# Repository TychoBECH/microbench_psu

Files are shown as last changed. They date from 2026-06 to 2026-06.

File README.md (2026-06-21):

# Bench PSU

A bench power supply built around a PIC18F16Q40, split across three boards: a main board (power supply, MCU, USB), a UI board (rotary encoder + buttons), and a display board (7-segment display + LEDs). Voltage (0-24 V) and current (0-2 A) are set via the encoder and a DAC, with live measurement readback through three I2C ADCs. Firmware features include EEPROM-backed setpoint persistence, automatic over-temperature shutdown, a standby/sleep mode, and a SCPI-style ASCII command interface over UART for remote control and automated testing. The enclosure is 3D-printed.

## Repository structure

```
firmware/microbench_psu.X/      MPLAB X project (PIC18F16Q40, XC8)
hardware/electrical/            Altium Designer projects, one per board
  main-board/                     Power supply, MCU, USB
    Parts_Library/                  Shared component library (git submodule)
  ui-board/                       Rotary encoder and buttons
  display-board/                  7-segment display and LEDs
hardware/mechanical/            SolidWorks enclosure and 3D-printed parts
hardware/bom/                   Bill of materials
docs/                            Pinout tables, SCPI command reference, notes
```

## Building the firmware

Open `firmware/microbench_psu.X` in MPLAB X IDE and build as usual. The project uses MPLAB Code Configurator (MCC) generated drivers under `mcc_generated_files/`, plus a set of hand-written modules (`display`, `encoder`, `adc`, `psu`, `eeprom_settings`, `scpi`, `i2c_bus`, `mcp47cxdx`) — see `firmware/microbench_psu.X/main.c` for the top-level control flow.

## Hardware

Each board under `hardware/electrical/` is its own Altium Designer project; see the README in each board's folder for what it covers. The main board references a shared component library as a git submodule — after cloning this repo, run:

```
git submodule update --init --recursive
```

to pull it in.

`hardware/mechanical/` holds the SolidWorks enclosure (front/back covers, knob, lightpipe) with STL/STEP exports for printing or referencing in other CAD tools.

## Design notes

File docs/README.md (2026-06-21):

# Documentation

- [SCPI command reference](scpi-reference.md) — UART command interface for remote control and automated testing

Pinout tables and other notes go here.

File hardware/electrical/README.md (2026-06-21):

# Electrical

Three separate Altium Designer projects, one per board:

| Folder | Board |
|---|---|
| `main-board/` | Power supply, MCU, USB |
| `ui-board/` | Encoder and buttons |
| `display-board/` | Display and LEDs |

Each board folder holds its own Altium project files (`.PrjPcb`, `.SchDoc`, `.PcbDoc`, etc.) plus an `outputs/` subfolder for generated manufacturing/assembly outputs (gerbers, NC drill files, STEP exports). Treat `outputs/` as regenerable, not source of truth.

The main board references a shared component library (schematic symbols, PCB footprints, 3D models) as a git submodule at `main-board/Parts_Library/`, pulled from a separate repo. After cloning, run `git submodule update --init --recursive` to fetch it.

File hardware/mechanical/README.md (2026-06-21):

# Mechanical

SolidWorks enclosure for the PSU.

- `Assembly_microbench_psu.SLDASM` — top-level assembly
- `Front Cover.SLDPRT`, `Back Cover.SLDPRT` — main enclosure shells
- `Knob.SLDPRT` — encoder knob
- `Lightpipe.SLDPRT` — light pipe for the front panel LEDs

## exports/

Print-ready and interchange exports. Treat this as regenerable output, not source of truth.

- `stl/` — print-ready meshes for the enclosure parts (covers, bezel, case, knob)
- `stp/` — STEP exports, including board outlines imported from each Altium project (`main-board.step`, `ui-board.step`, `display-board.step`) for mechanical fit-checking, plus third-party part models (e.g. `1455J801BK.step` for the enclosure base)

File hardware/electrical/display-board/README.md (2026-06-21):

# Display board

7-segment display and LEDs.

Altium project: `display-board.PrjPcb` / `display-board.PcbDoc` / `display-board.SchDoc`.

Generated outputs (gerbers, NC drill files, STEP export) are in `outputs/`.

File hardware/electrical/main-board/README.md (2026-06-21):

# Main board

Power supply (DC/DC conversion, adjustable output stage), MCU (PIC18F16Q40), and USB.

Altium project: `main-board.PrjPcb` / `main-board.PcbDoc`, with schematic sheets covering the overview, the adjustable DC/DC converter, the output stage, and USB. References the shared `Parts_Library/` submodule for schematic symbols, footprints, and 3D models.

Generated outputs (gerbers, NC drill files, STEP export) are in `outputs/`.

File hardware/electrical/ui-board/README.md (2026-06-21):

# UI board

Rotary encoder and buttons.

Altium project: `ui-board.PrjPcb` / `ui-board.PcbDoc` / `ui-board.SchDoc`.

Generated outputs (gerbers, NC drill files, STEP export) are in `outputs/`.

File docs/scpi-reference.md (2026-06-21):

# SCPI command reference

The firmware exposes a SCPI-style ASCII command interface over UART1.

## Line format

- Commands are terminated with `\r`, `\n`, or both.
- Commands are case-insensitive (the parser uppercases the line before matching).
- Numeric arguments are decimal, e.g. `12.5`, with up to 3 fractional digits; extra digits beyond the third are ignored.
- Responses are terminated with `\r\n`.
- An unrecognized command returns `ERR\r\n`.

There's no command queueing or interrupt-driven UART reception — once a line starts arriving, the firmware blocks (up to ~200 ms) until it's complete or times out, before resuming the front-panel update loop. See `firmware/microbench_psu.X/scpi.c` for the details.

## Commands

| Command | Description |
|---|---|
| `*IDN?` | Returns identification string: `TychoBECH,MicrobenchPSU,1,1.0` |
| `*RST` | Disables the output and resets both setpoints to 0 |
| `OUTP ON` / `OUTPUT ON` | Enables the output |
| `OUTP OFF` / `OUTPUT OFF` | Disables the output |
| `OUTP?` / `OUTPUT?` | Queries output state: `1` (on) or `0` (off) |
| `VOLT <value>` / `VOLTAGE <value>` | Sets the voltage setpoint, in volts (e.g. `VOLT 12.5`). Clamped to 0-24 V |
| `VOLT?` / `VOLTAGE?` | Queries the voltage setpoint, in volts |
| `CURR <value>` / `CURRENT <value>` | Sets the current limit setpoint, in amps (e.g. `CURR 0.5`). Clamped to 0-2 A |
| `CURR?` / `CURRENT?` | Queries the current limit setpoint, in amps |
| `MEAS:VOLT?` / `MEASURE:VOLTAGE?` | Returns the measured output voltage, in volts |
| `MEAS:CURR?` / `MEASURE:CURRENT?` | Returns the measured output current, in amps |
| `MEAS:TEMP?` / `MEASURE:TEMPERATURE?` | Returns the measured regulator temperature, in degC |
| `SYST:ERR?` / `SYSTEM:ERROR?` | Returns `OVERTEMP` if the over-temperature protection has tripped, otherwise `0` |

Accepted forms for `OUTP`/`OUTPUT` arguments: `ON` / `1` to enable, `OFF` / `0` to disable.

## Notes

- `OUTP ON` is refused (silently ignored) while the over-temperature protection is active. Check `SYST:ERR?` if the output won't turn on.
- `VOLT`/`CURR` writes (whether from SCPI or the front panel) are debounced before being saved to EEPROM — the value is committed about 5 seconds after the last change, so rapid scripted setpoint sweeps don't wear out the EEPROM on every step.
- Setpoint and measurement values share the same 3-decimal formatting (e.g. `12.500`), regardless of the underlying ADC resolution.

## Example session

```
*IDN?
TychoBECH,MicrobenchPSU,1,1.0

VOLT 5.0
CURR 0.5
OUTP ON
OUTP?
1

MEAS:VOLT?
4.998
MEAS:CURR?
0.102
MEAS:TEMP?
28.400

OUTP OFF
```

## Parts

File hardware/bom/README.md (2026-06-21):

# Bill of Materials

Component list / BOM for the power supply goes here.

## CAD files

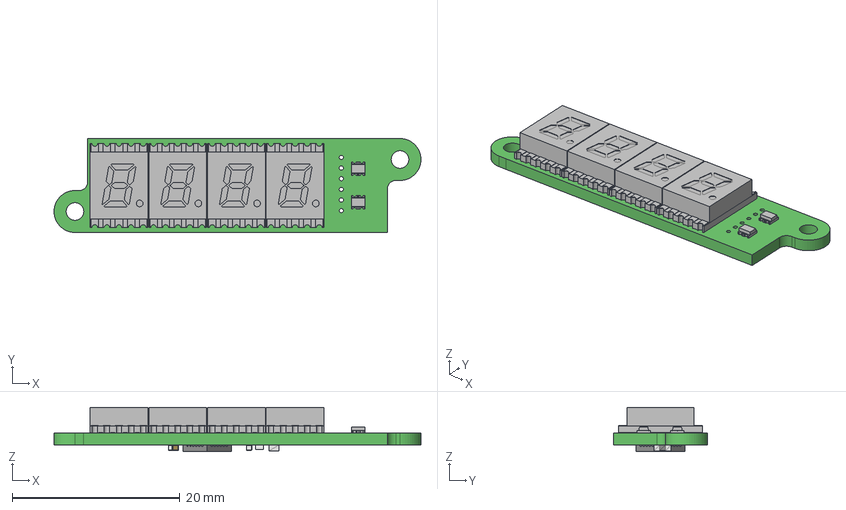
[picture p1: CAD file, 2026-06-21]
hardware/electrical/display-board/outputs/ExportSTEP/display-board.step
43.8 x 11.2 x 5.28 mm
pole x 2
contact x 2
lense x 2
ACSX02-41_RGB8421504 x 4
Mid Body
Mark
Thermal Shape
RC0805N

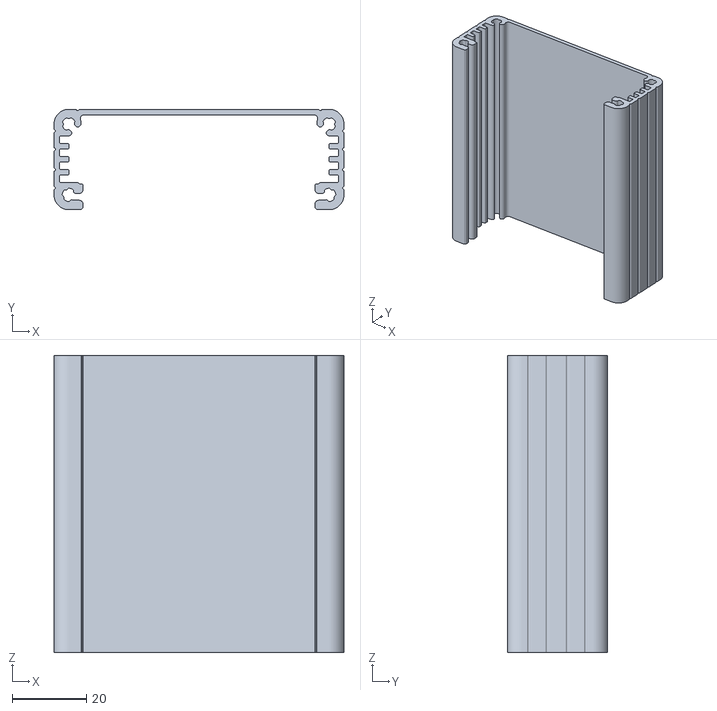
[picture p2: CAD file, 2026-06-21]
hardware/mechanical/exports/stl/Case.stl
78.0 x 27.0 x 80.0

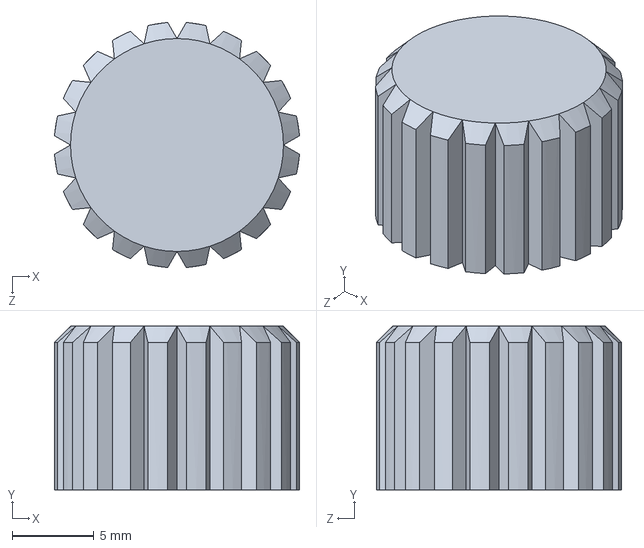
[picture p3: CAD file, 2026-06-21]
hardware/mechanical/Knob.SLDPRT
15.0 x 10.0 x 15.0 mm

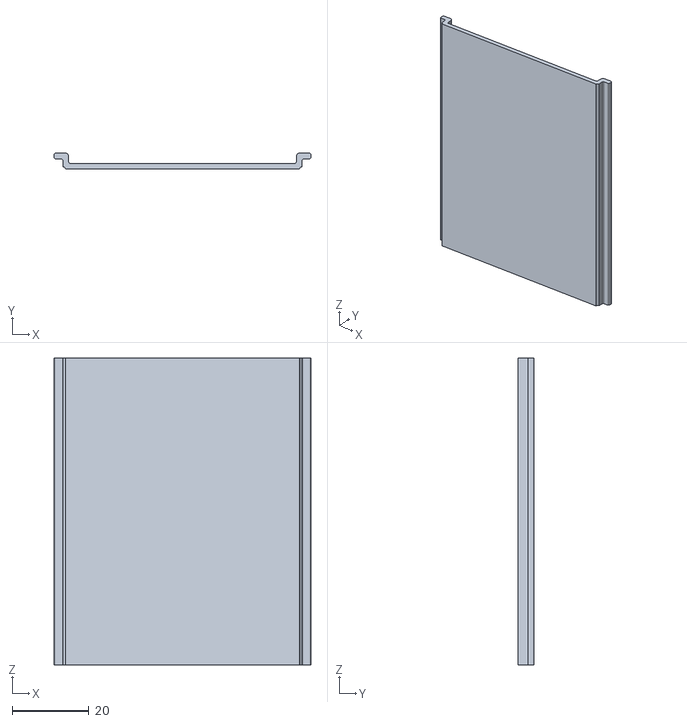
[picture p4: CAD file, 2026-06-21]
hardware/mechanical/exports/stl/Bottom_cover.stl
66.9 x 4.29 x 80.0

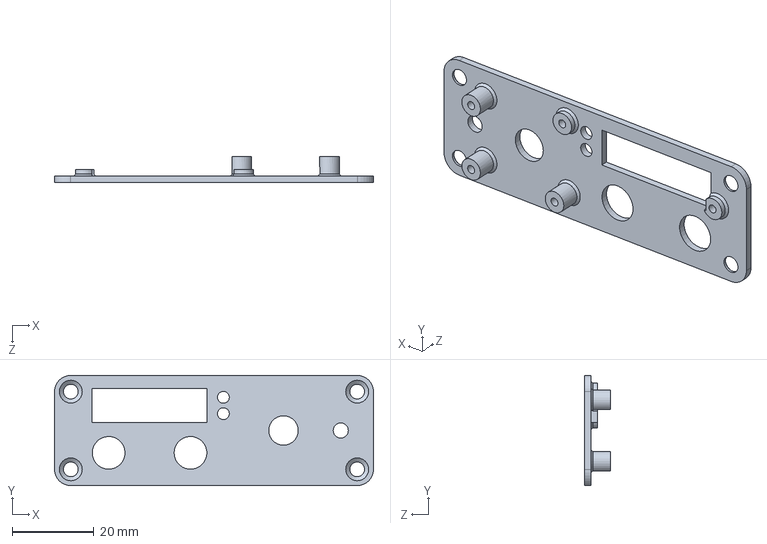
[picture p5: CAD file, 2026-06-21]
hardware/mechanical/Front Cover.SLDPRT
78.0 x 26.9 x 6.30 mm

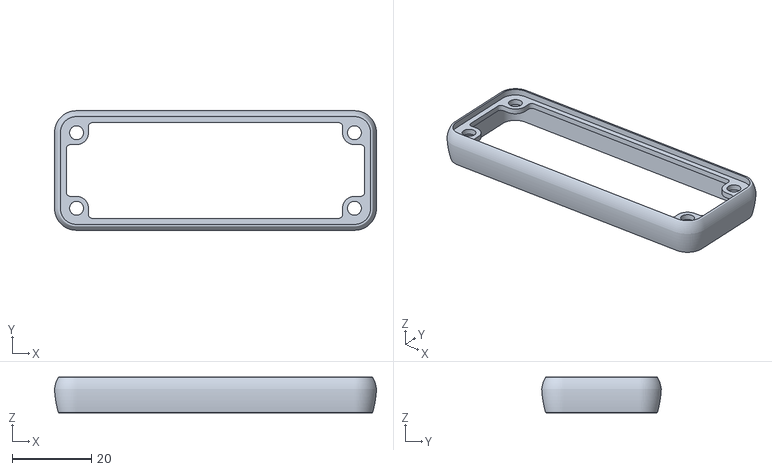
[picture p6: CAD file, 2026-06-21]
hardware/mechanical/exports/stl/Bezel.stl
81.1 x 30.1 x 9.00

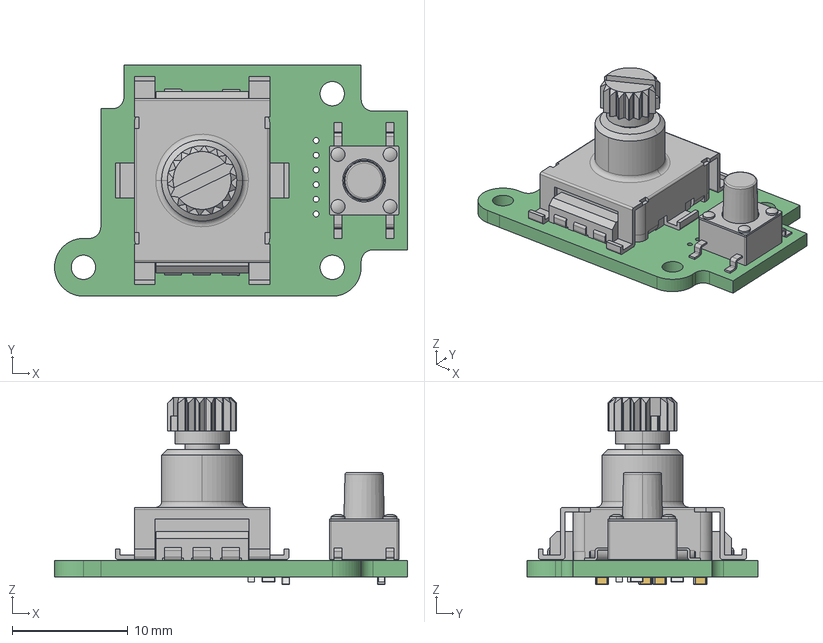
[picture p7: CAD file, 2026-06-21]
hardware/mechanical/exports/stp/ui-board.step
30.5 x 20.0 x 16.2 mm
PEC11S-929K-S0015_RGB8421504
Same_Sky_TS04-66-75-BK-160-SMT_RGB8421504
Mid_Body x 6
Mark x 6

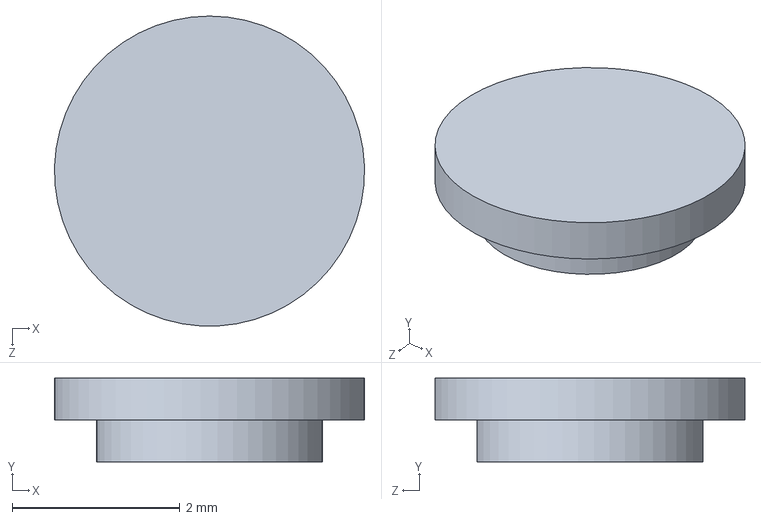
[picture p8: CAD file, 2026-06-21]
hardware/mechanical/Lightpipe.SLDPRT
3.70 x 1.00 x 3.70 mm

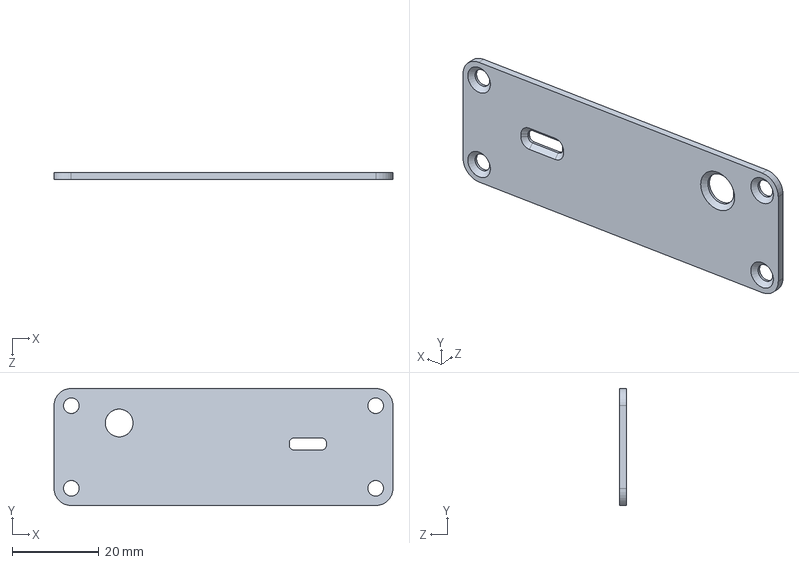
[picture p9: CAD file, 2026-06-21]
hardware/mechanical/Back Cover.SLDPRT
78.0 x 26.9 x 1.50 mm

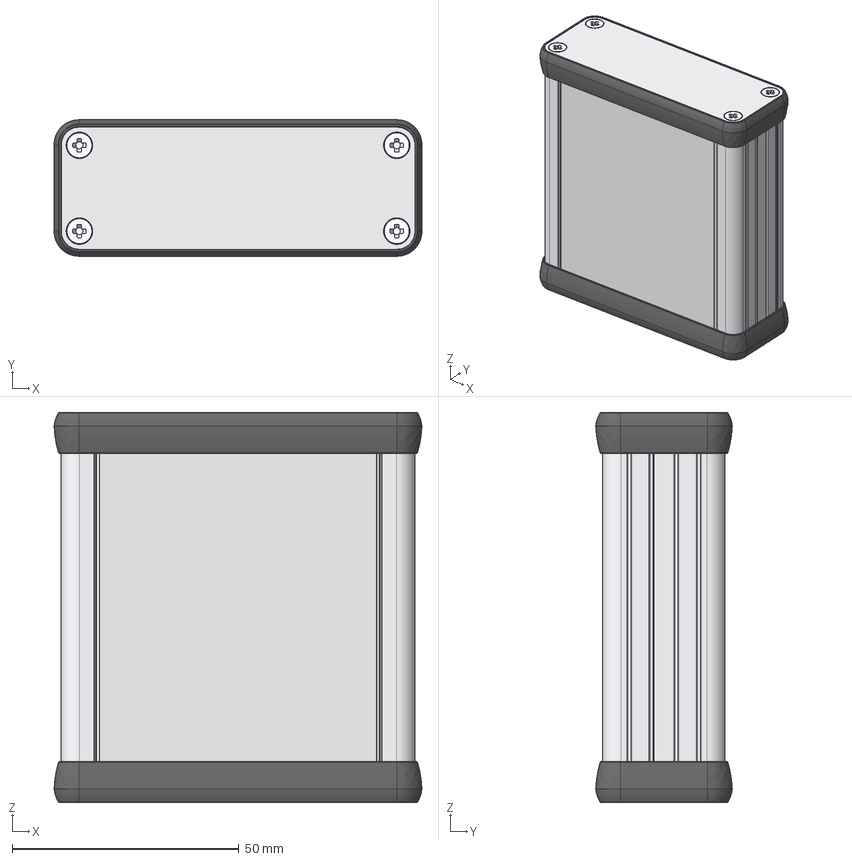
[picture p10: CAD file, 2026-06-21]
hardware/mechanical/exports/stp/1455J801BK.step
81.1 x 30.1 x 86.0 mm
J Channel Extrusion 80mm
J Cap Extrusion 80mm
K Bezel x 2
K1 End Panel x 2
1455 screw x 8

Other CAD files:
hardware/mechanical/exports/stl/Back_cover.STL
hardware/mechanical/exports/stl/Front_cover.STL
hardware/mechanical/exports/stl/Knob.STL

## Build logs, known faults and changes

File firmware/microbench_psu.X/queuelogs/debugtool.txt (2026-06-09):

2723 1780426053673 XXXX 1780426053673, Thread 2723: com.Send returned false 
2723 1780426053673 XXXX 1780426053673, Thread 2723: execCommand: exception after writeSideChanel null 
2723 1780426053673 GEN4_CONNECT_DIAGNOSTICS:Removing plug and play observer com.microchip.mplab.mdbcore.RI4Tool.RI4ToolBase$RI4PlugNPlayObserver@68eca286
2723 1780426053673 GEN4_CONNECT_DIAGNOSTICS:Begin PlugNPlayObservers list dump:
2723 1780426053673 GEN4_CONNECT_DIAGNOSTICS:End PlugNPlayObservers list dump:

2736 1780426053673 GEN4_TO_CONTROLLER_LOG:GEN4_DEBUG_INT_LOG_PIC18F16Q40 Pre:DebugReadTargetMemory
2736 1780426053673 GEN4_TO_CONTROLLER_LOG:GEN4_DEBUG_INT_LOG_PIC18F16Q40 Payload
2736 1780426053673 GEN4_TO_CONTROLLER_LOG:GEN4_DEBUG_INT_LOG_PIC18F16Q40 FileRegs
2736 1780426053673 GEN4_TO_CONTROLLER_LOG:GEN4_DEBUG_INT_LOG_PIC18F16Q40 4d8
2736 1780426053673 GEN4_TO_CONTROLLER_LOG:GEN4_DEBUG_INT_LOG_PIC18F16Q40 4d8
2736 1780426053673 GEN4_TO_CONTROLLER_LOG:GEN4_DEBUG_INT_LOG_PIC18F16Q40 Length = 1
2736 1780426053673 GEN4_TO_CONTROLLER_LOG:GEN4_DEBUG_INT_LOG_PIC18F16Q40 Payload End
2736 1780426053673 XXXX 1780426053673, Thread 2736: XXXX 1780426053673, Entering Thread 2736: Commands::runScriptWithUpload, script name = ReadRAM  
2736 1780426053673 XXXX 1780426053673, Thread 2736: XXXX 1780426053673, Entering Thread 2736: ToolCommUsb::readTransfer, sideData is 0x25 bytes long, transferDataLength is 0x1 bytes long  
2736 1780426053674 XXXX 1780426053674, Thread 2736: com.Send returned false 
2736 1780426053674 XXXX 1780426053674, Thread 2736: readTransfer: exception after writeHeaderAndGetAck null 
2736 1780426053674 XXXX 1780426053674, Thread 2736: XXXX 1780426053674, Entering Thread 2736: ToolCommUsb::recoverFromProtocolError, type = NO_SCRIPT  
2736 1780426053674 XXXX 1780426053674, Thread 2736: Send Abort Script Engine Command 
2736 1780426053674 XXXX 1780426053674, Thread 2736: XXXX 1780426053674, Entering Thread 2736: ToolCommUsb::killScriptEngine  
2736 1780426053675 XXXX 1780426053675, Thread 2736: com.Send returned false 
2736 1780426053675 XXXX 1780426053675, Thread 2736: Failed sending Abort Script Engine Command. Set nuclear option = true 
2736 1780426053675 XXXX 1780426053675, Thread 2736: About to nuke 
2736 1780426053675 XXXX 1780426053675, Thread 2736: XXXX 1780426053675, Entering Thread 2736: ToolCommUsb::nuclearOption  
2736 1780426053676 XXXX 1780426053675, Thread 2736: com.Send returned false

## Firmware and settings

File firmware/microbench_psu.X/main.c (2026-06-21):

/*
 * MAIN Generated Driver File
 *
 * @file main.c
 *
 * @defgroup main MAIN
 *
 * @brief This is the generated driver implementation file for the MAIN driver.
 *
 * @version MAIN Driver Version 1.0.0
 */

/*
(c) [2026] Microchip Technology Inc. and its subsidiaries.

	Subject to your compliance with these terms, you may use Microchip
	software and any derivatives exclusively with Microchip products.
	You are responsible for complying with 3rd party license terms
	applicable to your use of 3rd party software (including open source
	software) that may accompany Microchip software. SOFTWARE IS "AS IS."
	NO WARRANTIES, WHETHER EXPRESS, IMPLIED OR STATUTORY, APPLY TO THIS
	SOFTWARE, INCLUDING ANY IMPLIED WARRANTIES OF NON-INFRINGEMENT,
	MERCHANTABILITY, OR FITNESS FOR A PARTICULAR PURPOSE. IN NO EVENT
	WILL MICROCHIP BE LIABLE FOR ANY INDIRECT, SPECIAL, PUNITIVE,
	INCIDENTAL OR CONSEQUENTIAL LOSS, DAMAGE, COST OR EXPENSE OF ANY
	KIND WHATSOEVER RELATED TO THE SOFTWARE, HOWEVER CAUSED, EVEN IF
	MICROCHIP HAS BEEN ADVISED OF THE POSSIBILITY OR THE DAMAGES ARE
	FORESEEABLE. TO THE FULLEST EXTENT ALLOWED BY LAW, MICROCHIP'S
	TOTAL LIABILITY ON ALL CLAIMS RELATED TO THE SOFTWARE WILL NOT
	EXCEED AMOUNT OF FEES, IF ANY, YOU PAID DIRECTLY TO MICROCHIP FOR
	THIS SOFTWARE.
 */
#include "mcc_generated_files/system/system.h"
#include "mcc_generated_files/timer/tmr4.h"
#include "display.h"
#include "encoder.h"
#include "adc.h"
#include "psu.h"
#include "scpi.h"
#include <stdbool.h>
#include <stdint.h>

#define VOLTAGE_STEP_MV  50
#define CURRENT_STEP_MA  5

#define SETPOINT_DISPLAY_TICKS  20  // 20 @ 50 ms = 1.0 s
#define LONG_PRESS_TICKS        20  // 20 @ 50 ms = 1.0 s

typedef enum {
	EDIT_VOLTAGE,
	EDIT_CURRENT
} edit_mode_t;

int main(void) {
	SYSTEM_Initialize();

	TMR4_OverflowCallbackRegister(encoder_task);
	INTERRUPT_GlobalInterruptEnable();

	Display_Init();
	PSU_Init();

	edit_mode_t edit_mode = EDIT_VOLTAGE;
	bool standby = false;
	uint8_t setpoint_display_timer = 0;
	uint8_t long_press_counter = 0;
	uint8_t led_flash_counter = 0;

	uint8_t prev_btn_enc    = 1;
	uint8_t prev_btn_enable = 1;

	while (1) {
		CLRWDT(); // pet the watchdog once per loop pass (~50 ms normally, bounded well under the ~2 s WDT period)
		SCPI_Task();

		uint8_t btn_enc    = IO_RC4_GetValue();
		uint8_t btn_enable = IO_RC3_GetValue();

		// --- standby mode ---
		if (standby) {
			// wake on falling edge only and ignores the held button that triggered sleep
			if ((!btn_enc && prev_btn_enc) || (!btn_enable && prev_btn_enable)) {
				standby = false;
				long_press_counter = 0;
			}
			prev_btn_enc    = btn_enc;
			prev_btn_enable = btn_enable;
			__delay_ms(50);
			continue;
		}

		// --- long press detection on encoder button (RC4) ---
		if (!btn_enc) {
			long_press_counter++;
			if (long_press_counter >= LONG_PRESS_TICKS) {
				// enter standby
				standby = true;
				long_press_counter = 0;
				PSU_SetOutputEnabled(false);
				displayBlank();
				setLeds(LED_OFF, LED_OFF);
				prev_btn_enc    = btn_enc;
				prev_btn_enable = btn_enable;
				__delay_ms(50);
				continue;
			}
		} else {
			// --- short press: released before long press threshold ---
			if (prev_btn_enc == 0 && long_press_counter < LONG_PRESS_TICKS) {
				PSU_SetOutputEnabled(!PSU_IsOutputEnabled());
			}
			long_press_counter = 0;
		}

		// --- enable button (RC3): cycle V/A ---
		if (!btn_enable && prev_btn_enable) {
			edit_mode = (edit_mode == EDIT_VOLTAGE) ? EDIT_CURRENT : EDIT_VOLTAGE;
		}

		prev_btn_enc    = btn_enc;
		prev_btn_enable = btn_enable;

		// --- encoder ---
		int16_t delta = encoder_get_delta();
		if (delta != 0) {
			if (edit_mode == EDIT_VOLTAGE) {
				int32_t new_v = (int32_t)PSU_GetVoltageSetpoint() + (int32_t)delta * VOLTAGE_STEP_MV;
				if (new_v < VOLTAGE_MIN_MV) new_v = VOLTAGE_MIN_MV;
				PSU_SetVoltageSetpoint((uint16_t)new_v);
			} else {
				int32_t new_i = (int32_t)PSU_GetCurrentSetpoint() + (int32_t)delta * CURRENT_STEP_MA;
				if (new_i < CURRENT_MIN_MA) new_i = CURRENT_MIN_MA;
				PSU_SetCurrentSetpoint((uint16_t)new_i);
			}
			if (PSU_IsOutputEnabled()) setpoint_display_timer = SETPOINT_DISPLAY_TICKS;
		}
		if (setpoint_display_timer > 0) setpoint_display_timer--;

		// --- PSU housekeeping: over-temperature protection + deferred EEPROM write ---
		PSU_Task();

		// --- display ---
		if (PSU_IsOverTemp()) {
			writeDisplay(PSU_GetTempC());
			writeUnit(UNIT_Volts); // no temperature unit symbol available, blank is clearest
			displayCommit();
		} else {
			bool show_setpoint = !PSU_IsOutputEnabled() || (setpoint_display_timer > 0);

			if (edit_mode == EDIT_VOLTAGE) {
				float display_val = show_setpoint
					? PSU_GetVoltageSetpoint() / 1000.0f
					: ADC_ReadVoltageV();
				writeDisplay(display_val);
				writeUnit(UNIT_Volts);
			} else {
				float display_val = show_setpoint
					? PSU_GetCurrentSetpoint() / 1000.0f
					: ADC_ReadCurrentA();
				writeDisplay(display_val);
				writeUnit(UNIT_Amps);
			}
			displayCommit();
		}

		// --- LEDs: both flash green when output on, both off when output off ---
		led_flash_counter++;
		if (PSU_IsOutputEnabled()) {
			uint8_t led = (led_flash_counter & 0x08) ? LED_GREEN : LED_OFF;
			setLeds(led, led);
		} else {
			setLeds(LED_OFF, LED_OFF);
		}

		__delay_ms(50);
	}
}

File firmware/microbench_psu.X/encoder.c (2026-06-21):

#include "encoder.h"
#include "mcc_generated_files/system/pins.h"

static const int8_t encoderLut[16] = {
	0, -1, 1, 0,
	1, 0, 0, -1,
	-1, 0, 0, 1,
	0, 1, -1, 0
};

static volatile int16_t encoder_delta = 0;
static uint8_t prev_state = 0;

static uint8_t encoder_read_pins(void) {
	uint8_t a = IO_RC7_GetValue();
	uint8_t b = IO_RC6_GetValue();
	return (uint8_t)((a << 1) | b);
}

void encoder_task(void) {
	uint8_t curr_state = encoder_read_pins();
	uint8_t index = (uint8_t)((prev_state << 2) | curr_state);
	encoder_delta += encoderLut[index];
	prev_state = curr_state;
}

int16_t encoder_get_delta(void) {
	int16_t delta = encoder_delta;
	encoder_delta = 0;
	return delta;
}

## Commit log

2026-06-09 Reduced I2C speed to 100kHz
2026-06-11 Added encoder to voltage and current setpoint
2026-06-11 Added power down
2026-06-11 Set LED to flash when output is on.
2026-06-12 Added over temperature protection
2026-06-16 Added UART via MCC
2026-06-21 Add bounded timeout to I2C transfers and fail-safe ADC fault handling
    A stuck bus or unresponsive sensor previously hung the firmware forever
    in I2C_Write/I2C_Read's busy-wait loop, with no way to recover (including
    the over-temperature shutdown path). I2C_Read/I2C_Write now give up after
    a bounded number of iterations and report failure.
    ADC_ReadRaw propagates that failure as the maximum raw ADC value rather
    than silently returning a low/zero reading, so a failed temperature read
    is treated as "hot" instead of incorrectly looking safe.
    [adc.c, i2c_bus.c]
2026-06-21 Enable watchdog timer to recover from firmware hangs
    WDTE was OFF, so any hang (e.g. a stuck loop that the new I2C timeout
    doesn't cover) would leave the PSU stuck indefinitely with whatever
    output state it had. WDT is now always on with a fixed ~2.1 s period,
    well above worst-case legitimate blocking (200 ms SCPI line timeout,
    bounded I2C retries), and petted once per main loop pass.
    [main.c]
2026-06-21 Remove stale placeholder comment on voltage ADC scaling
    The 12.15 mV/LSB value was already calibrated against the hardware
    voltage divider; only the comment still called it a placeholder.
2026-06-21 Replace all non-ASCII characters with plain ASCII equivalents
    The previous UTF-8 re-encoding fix didn't solve the display problem:
    the editor reading these files doesn't auto-detect UTF-8 and was
    decoding the (correct) UTF-8 bytes as Windows-1252, producing
    "mojibake" like "Â©". Microchip's MCC templates also bake in several
    already-corrupted characters (literal '?' where smart quotes/
    apostrophes used to be, mangled '(R)' trademark symbols).
    Replacing every non-ASCII character (c) -> (c), (R) -> (R), smart
    quotes -> straight quotes, degree sign -> "degC", em dash -> "--")
    sidesteps the encoding-detection problem entirely, since plain ASCII
    renders identically under every encoding.
    [adc.c]
2026-06-21 Added Altium projects and first solidworks parts
    [Adjustable_DCDC.SchDoc, Back Cover.SLDPRT, Bench PSU.PrjPcb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]
2026-06-21 Renamed Projet ui-board and generated outputs
    [Dsiplay_PCB.step, Encoder Board.PrjPcb, Encoder Board.SchDoc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]
2026-06-21 Renamed main-board and generated outputs
    [Bench PSU.PrjPcb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]
2026-06-21 Added mechanical Construction
    [1455J801BK.step, Back_cover.STL, Display Board.SchDoc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]
